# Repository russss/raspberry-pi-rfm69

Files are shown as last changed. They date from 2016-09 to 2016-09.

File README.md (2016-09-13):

# Raspberry Pi RFM69 Interface

This is a Raspberry Pi interface to the HopeRF RFM69 module, designed
for the [UKHASnet](https://ukhas.net) project.

It supports up to 4 channels with independent RFM69 transceivers, intended
for experimenting with sectored antennas and long-range backhaul links,
but can also be used with just a single RFM69 for more normal applications.

For code which works with this, check out my [rfm69
python library](https://github.com/russss/rfm69-python).

## BOM

To use just a single RFM69 channel, you will need:

* IC1: RFM69[H][W]
* J1: 40-pin socket (e.g. Farnell 7992033)
* P1: Edge-launch SMA socket

To use more than one RFM69, you'll additionally need:

* IC5: 3.3V 800mA regulator in SOT-223 package e.g. NCP1117 (Farnell 1652366)
* C1, C2: 10uF 0805 SMD capacitors
* IC6: 74HC139 Demultiplexer, TSSOP-16 (Farnell 2444981)
* Plus additional RFM69s and SMA sockets

To use one-wire sensors if you require a strong pull-up:

* R1: A 4k7 0805 SMD resistor

## Assembly

If you want to use a single RFM69, you'll need to bridge jumpers J1 and
J2. J1 connects the 3v3 bus to the RPi's (which will *just about* run
one RFM69 from my experience).

J2 bypasses the demultiplexer on the SPI chip select line and
connects it directly to the first RFM69.

## Pin Mappings

|Module | Interrupt (DIO0) | Reset  |
|---|---|---|
|1 | GPIO20 | GPIO21 |
|2 | GPIO02 | GPIO03 |
|3 | GPIO27 | GPIO22 |
|4 | GPIO19 | GPIO26 |

* 1-wire: GPIO4
* NSS Select: GPIO23 (bit 1), GPIO24 (bit 2)

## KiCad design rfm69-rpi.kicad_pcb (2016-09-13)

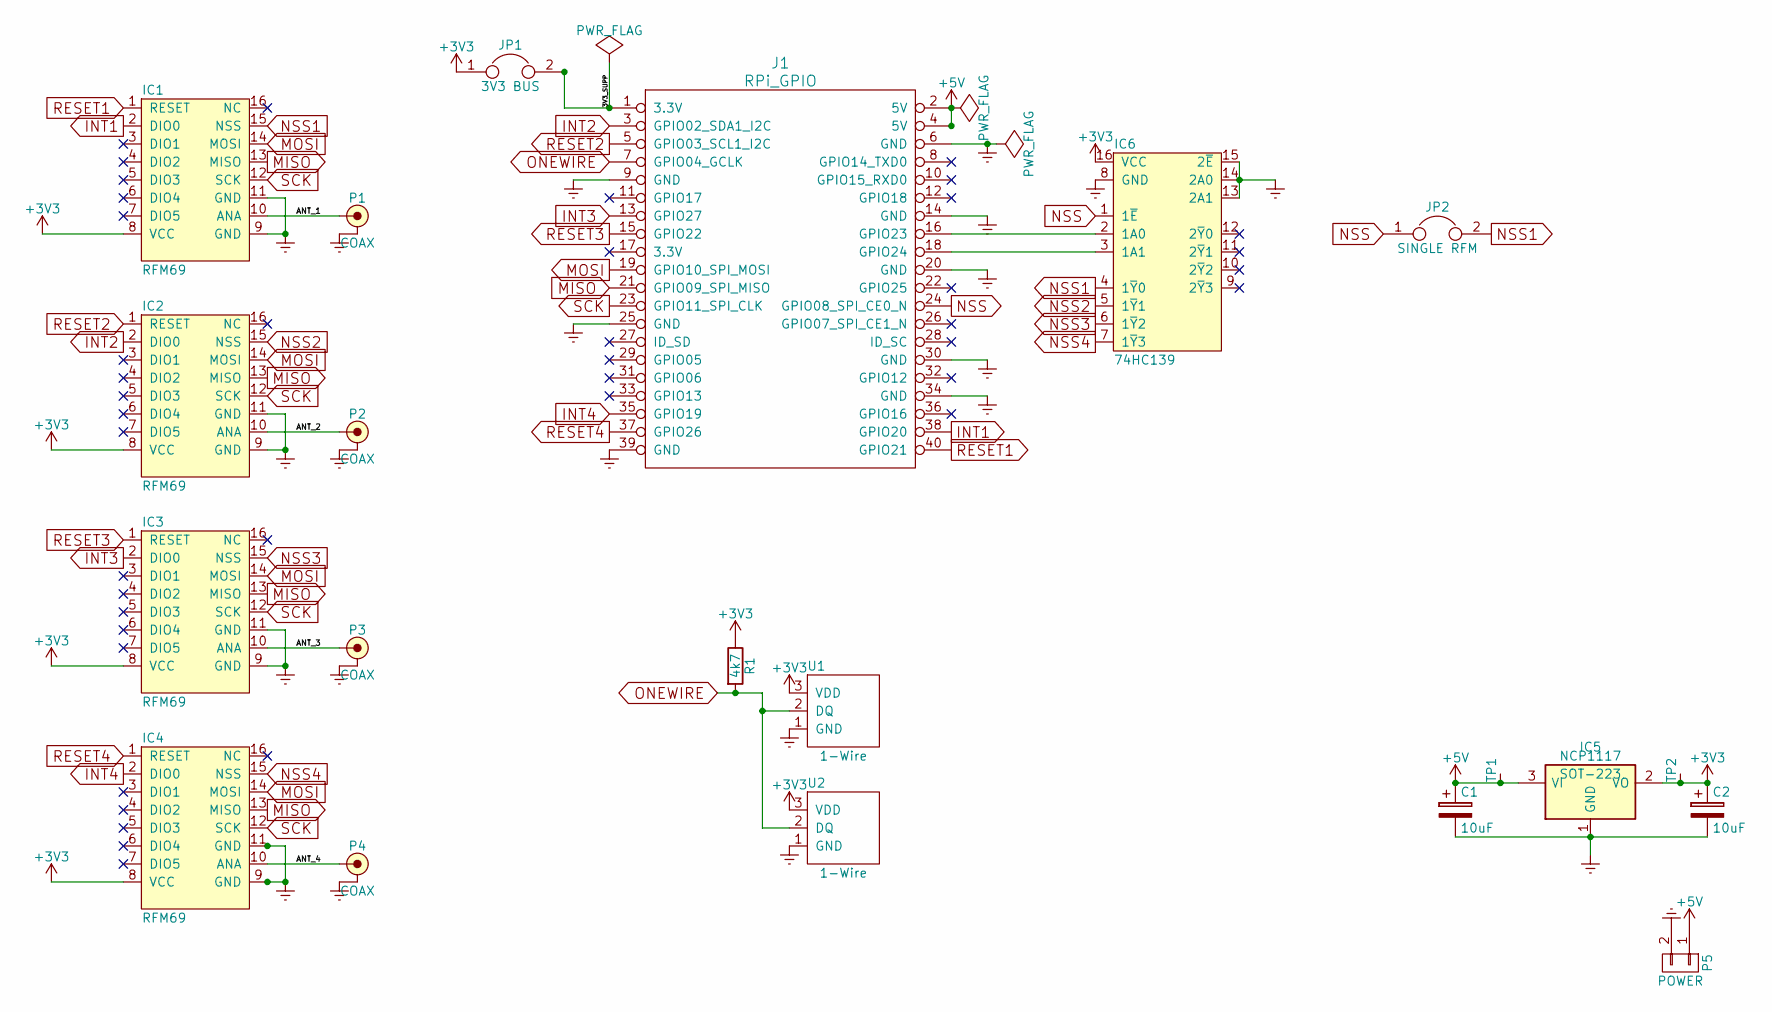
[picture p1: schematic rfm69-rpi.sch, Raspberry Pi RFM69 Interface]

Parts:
C1, C2: 10uF; C_0805
IC1, IC2, IC3, IC4: RFM69
IC5: NCP1117; SOT-223
IC6: 74HC139; TSSOP-16; Farnell 2444981
J1: RPi_GPIO; raspberrypi2
JP1: 3V3 BUS; TESTPT
JP2: SINGLE RFM; TESTPT
P1, P2, P3, P4: COAX; SMA-EDGE; Farnell 1608592
P5: POWER; JST-PH-SM4-2
R1: 4k7; 0805
TP1, TP2: TESTPAD
U1, U2: 1-Wire; TO-92_Molded_Narrow

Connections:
+3V3: C2.1, IC1.8 (VCC), IC2.8 (VCC), IC3.8 (VCC), IC4.8 (VCC), IC5.2 (VO), IC6.16 (VCC), JP1.1, R1.1, TP2.1, U1.3 (VDD), U2.3 (VDD)
+5V: C1.1, IC5.3 (VI), J1.2 (5V), J1.4 (5V), P5.1, TP1.1
/3V3_SUPP: J1.1 (3.3V), JP1.2
/ANT_1: IC1.10 (ANA), P1.1 (RF)
/ANT_2: IC2.10 (ANA), P2.1 (RF)
/ANT_3: IC3.10 (ANA), P3.1 (RF)
/ANT_4: IC4.10 (ANA), P4.1 (RF)
Earth: C1.2, C2.2, IC1.9 (GND), IC1.11 (GND), IC2.9 (GND), IC2.11 (GND), IC3.9 (GND), IC3.11 (GND), IC4.9 (GND), IC4.11 (GND), IC5.1 (GND), IC5.4, IC6.8 (GND), IC6.13 (2A1), IC6.14 (2A0), IC6.15 (2~E), J1.6 (GND), J1.9 (GND), J1.14 (GND), J1.20 (GND), J1.25 (GND), J1.30 (GND), J1.34 (GND), J1.39 (GND), P1.2 (GND), P2.2 (GND), P3.2 (GND), P4.2 (GND), P5.2, U1.1 (GND), U2.1 (GND)
INT1: IC1.2 (DIO0), J1.38 (GPIO20)
INT2: IC2.2 (DIO0), J1.3 (GPIO02_SDA1_I2C)
INT3: IC3.2 (DIO0), J1.13 (GPIO27)
INT4: IC4.2 (DIO0), J1.35 (GPIO19)
MISO: IC1.13 (MISO), IC2.13 (MISO), IC3.13 (MISO), IC4.13 (MISO), J1.21 (GPIO09_SPI_MISO)
MOSI: IC1.14 (MOSI), IC2.14 (MOSI), IC3.14 (MOSI), IC4.14 (MOSI), J1.19 (GPIO10_SPI_MOSI)
NSS: IC6.1 (1~E), J1.24 (GPIO08_SPI_CE0_N), JP2.1
NSS1: IC1.15 (NSS), IC6.4 (1~Y~0), JP2.2
NSS2: IC2.15 (NSS), IC6.5 (1~Y~1)
NSS3: IC3.15 (NSS), IC6.6 (1~Y~2)
NSS4: IC4.15 (NSS), IC6.7 (1~Y~3)
unnamed: IC6.2 (1A0), J1.16 (GPIO23)
unnamed: IC6.3 (1A1), J1.18 (GPIO24)
ONEWIRE: J1.7 (GPIO04_GCLK), R1.2, U1.2 (DQ), U2.2 (DQ)
RESET1: IC1.1 (RESET), J1.40 (GPIO21)
RESET2: IC2.1 (RESET), J1.5 (GPIO03_SCL1_I2C)
RESET3: IC3.1 (RESET), J1.15 (GPIO22)
RESET4: IC4.1 (RESET), J1.37 (GPIO26)
SCK: IC1.12 (SCK), IC2.12 (SCK), IC3.12 (SCK), IC4.12 (SCK), J1.23 (GPIO11_SPI_CLK)

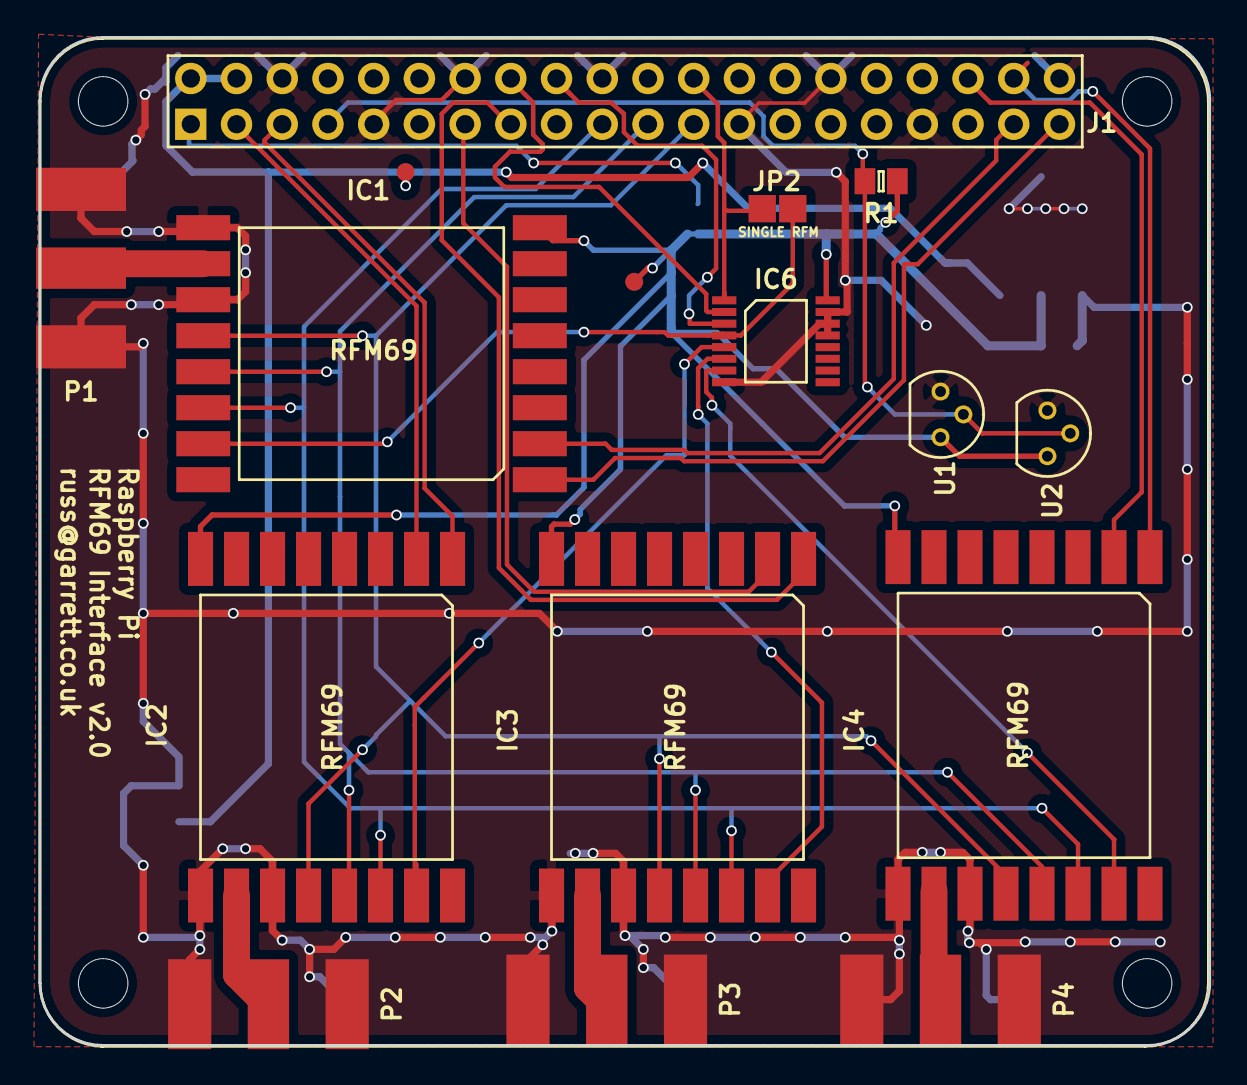
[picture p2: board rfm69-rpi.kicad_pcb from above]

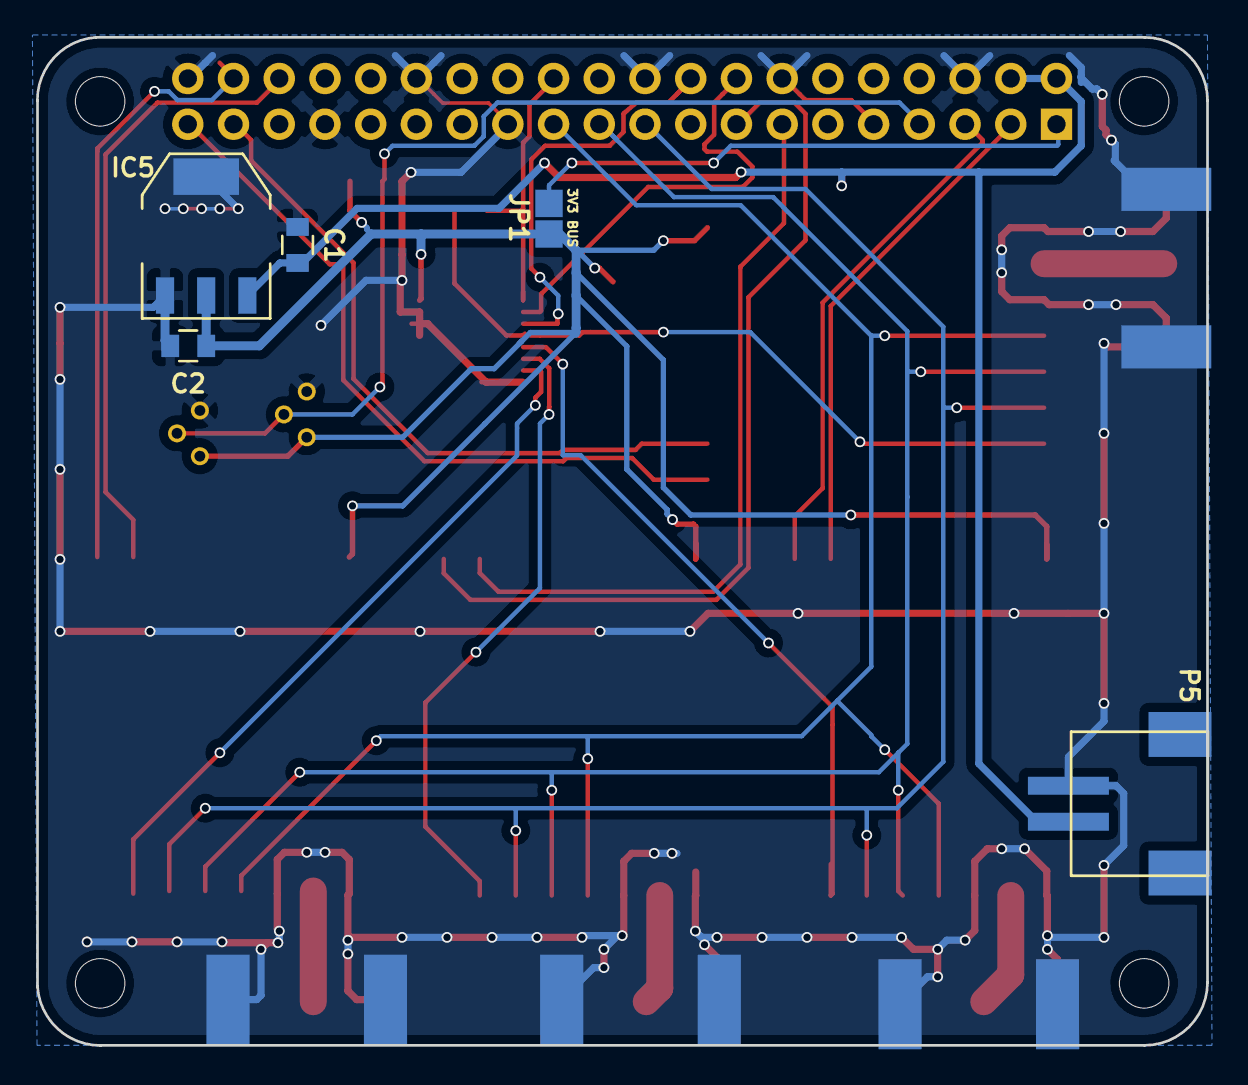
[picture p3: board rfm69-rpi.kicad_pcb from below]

Board: 2 copper layers, 65.0 x 56.0 mm, 21 parts (5 on the bottom side), 27 nets.

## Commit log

2016-09-12 Version 2
    [pi-hrf.brd, pi-hrf.sch, rfm69-rpi.kicad_pcb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]
2016-09-13 Version 2.0
    [rfm69-rpi.kicad_pcb, rfm69-rpi.sch]
